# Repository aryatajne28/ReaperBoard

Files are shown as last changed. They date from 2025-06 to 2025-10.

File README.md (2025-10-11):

# ReaperBoard - A unconventional Tenkeyless Keyboard

ReaperBoard-Complete_2025-Oct-11_01-16-08PM-000_CustomizedView284773604
c48fbb2a-0101-4329-bb91-416d34a26bfa
ReaperBoard-Complete_2025-Oct-11_01-21-18PM-000_CustomizedView34640921244

Features:
- 85x keys!
- Compact layout most suitable for coding.
- 87 RGB Neopixel, keep those RGB Animations coming...
- 0.91" OLED display to display anything you want.
- KMK firmware to edit those keymaps and all sorts of customization options.
- I preferred Tenkeyless design, because I already made a full-size Numpad in Hackpad V2!

## PCB 

The PCB's size is 360x130mm

| Schematic |
| - |
|  |

| Two sides |
| - |
|  |

| Front |
| - |
|  |

| Back |
| - |
|  |

3D render pictures:
| Bottom |
| - |
| a3b64d5b-69c6-4acd-ae06-55e119ac624c
  Keyboard-Bottom

 |
| Plate |
| - |
| c3e52580-ec77-43ca-8efa-2a3d8ef63d0d
  ReaperBoard-Plate |
| Top |
| - |
| ReaperBoard-Top_2025-Oct-11_01-17-54PM-000_CustomizedView19962291621 
ReaperBoard-Top|

## Complete Keyboard CAD

ReaperBoard-Complete_2025-Oct-11_01-16-08PM-000_CustomizedView284773604

The case was designed in Fusion360 by refering to the Hackpad case designing guide!

## BOM

BOM Sheet link: https://docs.google.com/spreadsheets/d/11-HGmM2KwnrwyEzwHYCNCNYylGgngtFtuS71F3h0WvA/edit?usp=sharing


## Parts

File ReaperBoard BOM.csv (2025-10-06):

ReaperBoard BOM
Sr. No. | Product | Name | Link | Unit Price | Quantity | Shipping | Total Price(INR) | (USD)
1 | Switches | Akko V3 Lavender Purple Pro Switch (Pack of 45) | https://stackskb.com/store/akko-v3-lavender-purple-pro-switch-pack-of-45/ | 999 | 2 | 0 | 1998 | 22.52160865
2 | Keycaps | Cotton Candy XDA Profile Keycaps | https://stackskb.com/store/cotton-candy-xda-profile-keycaps/ | 2,300 | 1 | 0 | 2300 | 25.92577572
3 | Stabilizers | Durock Clear Screw-In Stabilizers V2 | https://stackskb.com/store/durock-smokey-screw-in-stabilizers-v2/ | 1,595 | 1 | 0 | 1595 | 17.97896186
4 | M3 heat inserts | M3 * 4mm heat inserts | https://quartzcomponents.com/collections/nuts-bolts/products/m3-x-4mm-brass-heat-set-threaded-round-insert-nut-10-pcs | 28 | 1 | 0 | 28 | 0.3156181392
5 | OLED Screen | 0.91" OLED Screen | https://quartzcomponents.com/collections/oled/products/0-91-inch-128x32-blue-oled-display-module-with-i2c-iic-serial-interface | 110 | 1 | 50 | 160 | 1.803532224
6 | Neopixels | SK6812MINI-E | https://www.lcsc.com/product-detail/C5149201.html | 6 | 90 | 600 | 1140 | 12.8501671 | 14.96931746 | (Misc budget)
7 | PCB | PCB from JLCPCB | JLCPCB | 1934.43 | 1 | 2896.33 | 4830.76 | 54.45269579
8 | Raspberry Pi Pico | Orphues Pico | Hack Club HQ | 0 | 1 | 0 | 0 | 0
9 | Case | 3D Printed Case | Printing Legion | 0 | 1 | 0 | 0 | 0
Total Price |  |  |  |  |  |  | 12051.76 | 135.8483595
 |  |  |  |  |  |  | INR | USD
I will buy
1 | M3 Screws | M3 * 20mm Screws | https://quartzcomponents.com/collections/nuts-bolts/products/m3-x-20mm-csk-phillips-head-ss202-boltpack-of-10 | 20 | 1 | 0 | 20 | 0.225441528
2 | Diodes | 1N4148 Through Holes | https://quartzcomponents.com/products/1n4148-zener-diode?variant=42817413546218 | 2.1 | 100 | 0 | 210 | 2.367136044
3 | Capacitors | 10uF 0805 SMD Capacitors | https://quartzcomponents.com/products/10uf-10000nf-50v-0805-x7r-smd-capacitor-pack-of-5-pieces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 | 15 | 20 | 50 | 350 | 3.94522674
 |  |  |  |  |  |  | 580 | 6.537804312
 |  |  |  |  |  |  | INR | USD

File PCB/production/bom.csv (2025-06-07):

Designator | Footprint | Quantity | Value | LCSC Part #
C1 | 0805 | 1 | 1uf
C10, C11, C12, C13, C14, C15, C16, C17, C18, C19, C2, C20, C21, C22, C23, C24, C25, C26, C27, C28, C29, C3, C30, C31, C32, C33, C34, C35, C36, C37, C38, C39, C4, C40, C41, C42, C43, C44, C45, C46, C47, C48, C49, C5, C50, C51, C52, C53, C54, C55, C56, C57, C58, C59, C6, C60, C61, C62, C63, C64, C65, C66, C67, C68, C69, C7, C70, C71, C72, C73, C74, C75, C76, C77, C78, C79, C8, C80, C81, C82, C83, C84, C85, C86, C87, C88, C9 | 0805 | 87 | C
D1, D10, D11, D12, D13, D14, D15, D16, D17, D18, D19, D2, D20, D21, D22, D23, D24, D25, D26, D27, D28, D29, D3, D30, D31, D32, D33, D34, D35, D36, D37, D38, D39, D4, D40, D41, D42, D43, D44, D45, D46, D47, D48, D49, D5, D50, D51, D52, D53, D54, D55, D56, D57, D58, D59, D6, D60, D61, D62, D63, D64, D65, D66, D67, D68, D69, D7, D70, D71, D72, D73, D74, D75, D76, D77, D78, D79, D8, D80, D81, D82, D83, D84, D85, D9 | D_DO-35_SOD27_P7.62mm_Horizontal | 85 | D
D100, D101, D102, D103, D104, D105, D106, D107, D108, D109, D110, D111, D112, D113, D114, D115, D116, D117, D118, D119, D120, D121, D122, D123, D124, D125, D126, D127, D128, D129, D130, D131, D132, D133, D134, D135, D136, D137, D138, D139, D140, D141, D142, D143, D144, D145, D146, D147, D148, D149, D150, D151, D152, D153, D154, D155, D156, D157, D158, D159, D160, D161, D162, D163, D164, D165, D166, D167, D168, D169, D170, D171, D172, D86, D87, D88, D89, D90, D91, D92, D93, D94, D95, D96, D97, D98, D99 | SK6812MINI-E | 87 | SK6812MINI
J1 | SSD1306-0.91-OLED-4pin-128x32 | 1 | Conn_01x04_Pin
R1, R2 | 0805 | 2 | 4.7kΩ
SW1, SW10, SW11, SW12, SW13, SW14, SW15, SW16, SW17, SW18, SW19, SW2, SW20, SW21, SW22, SW23, SW24, SW25, SW26, SW27, SW29, SW3, SW30, SW31, SW33, SW34, SW35, SW36, SW37, SW38, SW39, SW4, SW40, SW41, SW42, SW43, SW44, SW46, SW47, SW48, SW5, SW50, SW51, SW52, SW53, SW54, SW55, SW56, SW57, SW58, SW59, SW6, SW60, SW63, SW64, SW65, SW66, SW67, SW68, SW69, SW7, SW70, SW71, SW72, SW74, SW8, SW83, SW84, SW85, SW9 | SW_Cherry_MX_PCB_1.00u | 70 | SW_Push
SW28 | SW_Cherry_MX_PCB_2.00u | 1 | SW_Push
SW32, SW45 | SW_Cherry_MX_PCB_1.50u | 2 | SW_Push
SW49 | SW_Cherry_MX_PCB_1.75u | 1 | SW_Push
SW61, SW62 | SW_Cherry_MX_PCB_2.25u | 2 | SW_Push
SW73 | SW_Cherry_MX_PCB_2.75u | 1 | SW_Push
SW75, SW76, SW77, SW79, SW80, SW81, SW82 | SW_Cherry_MX_PCB_1.25u | 7 | SW_Push
SW78 | SW_Cherry_MX_PCB_6.25u | 1 | SW_Push
U1 | RPi_Pico_SMD_TH | 1 | Pico

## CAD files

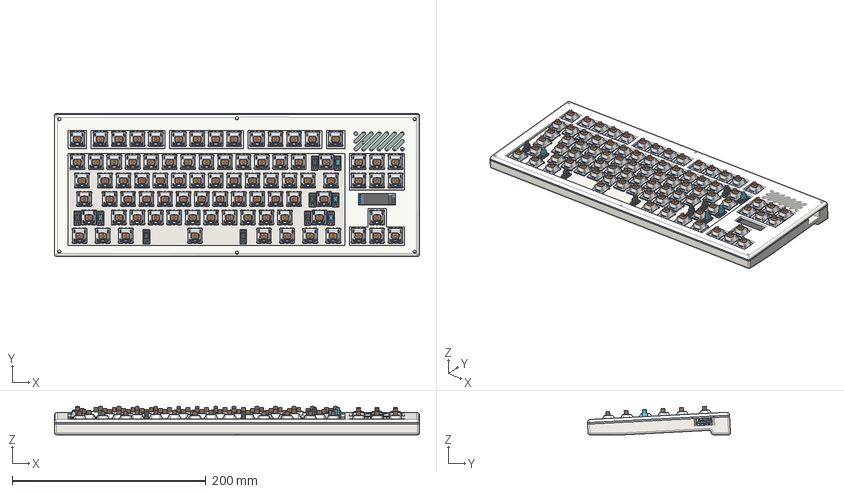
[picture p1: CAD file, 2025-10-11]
CAD/ReaperBoard-Complete.step
377.0 x 147.7 x 29.5 mm
SW_Cherry_MX_PCB x 85
C_0805_2012Metric x 88
D_DO-35_SOD27_P7.62mm_Horizontal x 85
OLED_0.91_128x32_1
Pin Header 4 x 1 TH 2.54mm Pitch
RESC-0603 x 13
2SD0601A
Stabilizer_Cherry_MX_2.00u x 4
Stabilizer_Cherry_MX_6.25u
R_0805_2012Metric x 2

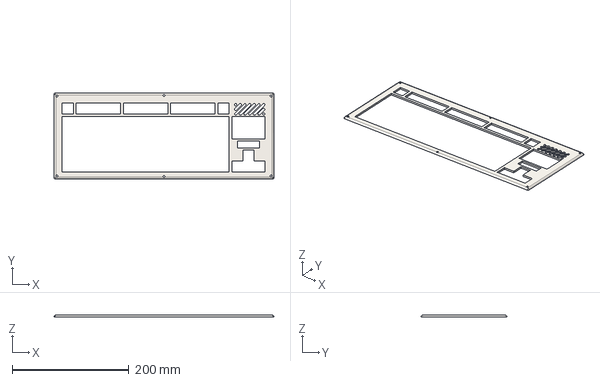
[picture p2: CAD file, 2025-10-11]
Production/ReaperBoard-Top.step
377.0 x 147.0 x 3.00 mm

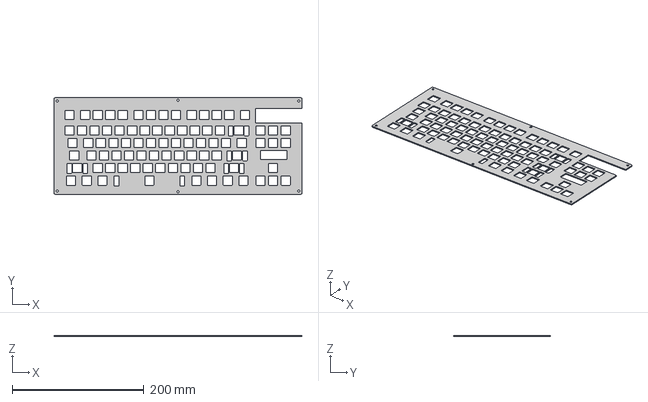
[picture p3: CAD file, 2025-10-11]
Production/ReaperBoard-Plate.step
377.0 x 147.0 x 1.60 mm

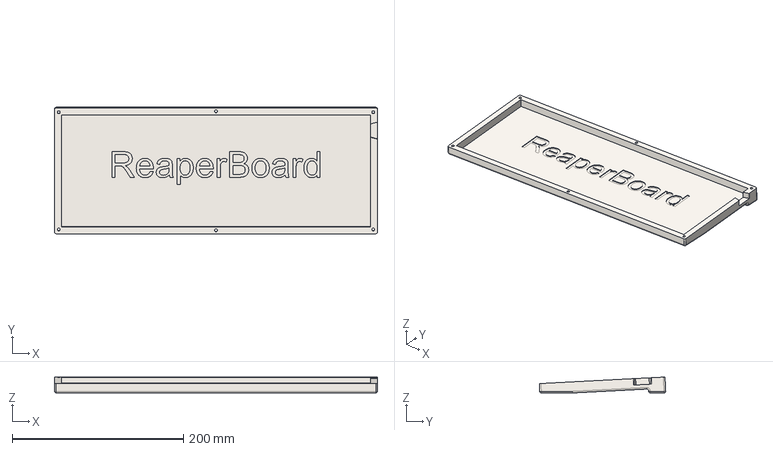
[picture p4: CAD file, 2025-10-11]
Production/ReaperBoard-Bottom.step
377.0 x 147.7 x 18.7 mm

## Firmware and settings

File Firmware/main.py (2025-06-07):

import board
import busio
import time
import board

from kmk.kmk_keyboard import KMKKeyboard
from kmk.keys import KC
from kmk.scanners import DiodeOrientation
from kmk.modules.macros import Macros
from kmk.extensions.display import Display, TextEntry, ImageEntry
from kmk.extensions.display.ssd1306 import SSD1306
from kmk.extensions.RGB import RGB
from kmk.extensions.rgb import AnimationModes
from kmk.extensions.media_keys import MediaKeys
from kmk.modules.mouse_keys import MouseKeys
from kmk.modules.layers import Layers


bus = busio.I2C(board.SCL, board.SDA);
driver = SSD1306(i2c=bus, device_address=0x3C);
display = Display(
    display=display_driver,
    entries=[
        TextEntry(text='ReaperBoard', x=0, y=0, y_anchor='M'),
    ],
    width=128,
    height=32,
    dim_time=10,
    dim_target=0.2,
    off_time=1200,
    brightness=0.7
);

keyboard = KMKKeyboard();

macros = Macros();
keyboard.extensions.append(display);
keyboard.extensions.append(MediaKeys())
keyboard.modules.append(macros);
keyboard.modules.append(MouseKeys())
keyboard.modules.append(Layers())

keyboard.col_pins = (board.D0, board.D1, board.D2, board.D3, board.D6, board.D7, board.D8, board.D9, board.D10, board.D11, board.D12, board.D13, board.D14, board.D15, board.D16, board.D17, board.D18);
keyboard.row_pins = (board.D19, board.D20, board.D21, board.D26, board.D27, board.D28);
keyboard.diode_orientation = DiodeOrientation.COL2ROW;

rgb = RGB(pixel_pin=board.D22, num_pixels=87, animation_speed=1, animation_mode=AnimationModes.STATIC, val_default=30, val_limit=40)
keyboard.extensions.append(rgb)

keyboard.keymap = [
    [
        KC.ESC , KC.MUTE, KC.VOLD, KC.VOLU, KC.MPRV, KC.MSTP, KC.MNXT, KC.BRID, KC.BRIU, KC.NO  , KC.NO  , KC.NO  , KC.NO  , KC.PSCR , KC.NO  , KC.NO  , KC.NO  ,
        KC.GRV , KC.N1  , KC.N2  , KC.N3  , KC.N4  , KC.N5  , KC.N6  , KC.N7  , KC.N8  , KC.N9  , KC.N0  , KC.MINS, KC.EQL , KC.BSPC, KC.INS  , KC.HOME  , KC.PDUP  ,
        KC.TAB , KC.Q   , KC.W   , KC.E   , KC.R   , KC.T   , KC.Y   , KC.U   , KC.I   , KC.O   , KC.P   , KC.LBRC, KC.RBTC, KC.BSLS, KC.DEL  , KC.END  , KC.PGDN  ,
        KC.CAPS , KC.A   , KC.S   , KC.D   , KC.F   , KC.G   , KC.H   , KC.J   , KC.K   , KC.L   , KC.SCLN, KC.QUOT, KC.NO , KC.ENT  , KC.NO  , KC.NO  , KC.NO  ,
        KC.LSFT, KC.Z   , KC.X   , KC.C   , KC.V   , KC.B   , KC.N   , KC.M   , KC.COMM, KC.DOT , KC.SLSH, KC.NO  , KC.NO  , KC.RSFT, KC.NO  , KC.UP  , KC.NO  ,
        KC.LCTRL, KC.LWIN, KC.LALT, KC.NO  , KC.NO  , KC.SPC , KC.NO  , KC.NO  , KC.RALT  , KC.RWIN, KC.MO(1), KC.RWIN,  KC.RCTRL  , KC.LEFT, KC.DOWN, KC.RGHT, 
    ],

    # Function keys
    [
        KC.ESC , KC.F1  , KC.F2  , KC.F3  , KC.F4  , KC.F5  , KC.F6  , KC.F7  , KC.F8  , KC.F9  , KC.F10 , KC.F11 , KC.F12 , KC.TRNS, KC.TRNS, KC.TRNS, KC.TRNS, 
        KC.TRNS, KC.TRNS, KC.TRNS, KC.TRNS, KC.TRNS, KC.TRNS, KC.TRNS, KC.TRNS, KC.TRNS, KC.TRNS, KC.TRNS, KC.TRNS, KC.TRNS, KC.TRNS, KC.TRNS, KC.TRNS, KC.TRNS, 
        KC.TRNS, KC.TRNS, KC.TRNS, KC.TRNS, KC.TRNS, KC.TRNS, KC.TRNS, KC.TRNS, KC.TRNS, KC.TRNS, KC.TRNS, KC.TRNS, KC.TRNS, KC.TRNS, KC.TRNS, KC.TRNS, KC.TRNS, 
        KC.TRNS, KC.TRNS, KC.TRNS, KC.TRNS, KC.TRNS, KC.TRNS, KC.TRNS, KC.TRNS, KC.TRNS, KC.TRNS, KC.TRNS, KC.TRNS, KC.TRNS, KC.TRNS, KC.TRNS, KC.TRNS, KC.TRNS, 
        KC.TRNS, KC.TRNS, KC.TRNS, KC.TRNS, KC.TRNS, KC.TRNS, KC.TRNS, KC.TRNS, KC.TRNS, KC.TRNS, KC.TRNS, KC.TRNS, KC.TRNS, KC.TRNS, KC.TRNS, KC.TRNS, KC.TRNS, 
        KC.TRNS, KC.TRNS, KC.TRNS, KC.TRNS, KC.TRNS, KC.TRNS, KC.TRNS, KC.TRNS, KC.TRNS, KC.TRNS, KC.TRNS, KC.TRNS, KC.TRNS, KC.TRNS, KC.TRNS, KC.TRNS, KC.TRNS, 
    ]
];

if __name__ == '__main__':
    keyboard.go();

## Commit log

2025-10-06 Update BOM with google sheet and image
2025-10-06 Added CSV of BOM
    [ReaperBoard BOM.csv]
2025-10-06 Update BOM Image
2025-10-06 upload new CSV file
    [ReaperBoard BOM.csv]
2025-10-11 Added new CAD files
    [ReaperBoard-Bottom.step, ReaperBoard-Complete.step, ReaperBoard-Plate.step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]
2025-10-11 Added new CAD files in Production folder
    [ReaperBoard-Bottom.step, ReaperBoard-Plate.step, ReaperBoard-Top.step]
